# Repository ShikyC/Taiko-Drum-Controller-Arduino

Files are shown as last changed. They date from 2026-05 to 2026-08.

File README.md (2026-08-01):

> **Legacy implementation archived:** the old Arduino/ATmega32U4 and earlier ESP32 implementation from `master` has reached end of life and is archived on the [`archive-arduino-legacy` branch](https://github.com/ShikyC/Taiko-Drum-Controller-Arduino/tree/archive-arduino-legacy). This branch documents the refactored ESP-IDF implementation.

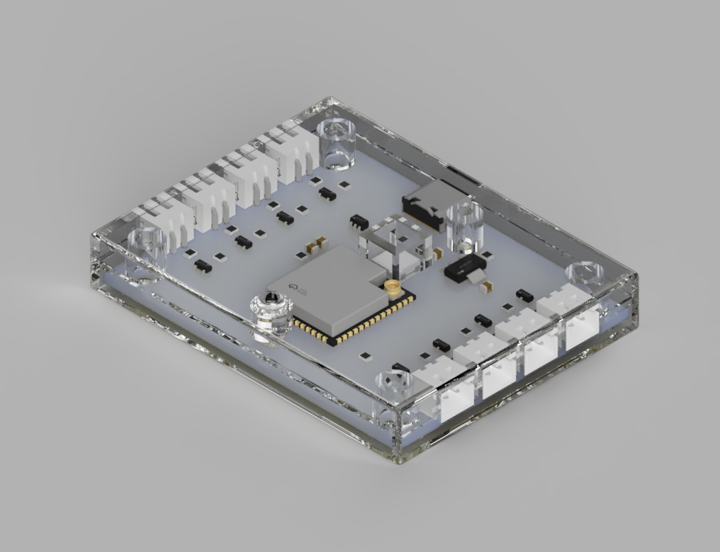
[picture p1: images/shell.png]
Taiko Drum Controller


# Taiko Drum Controller - ESP32-S3

Open-source firmware and hardware for building a USB taiko drum controller for PC play. Note that this controller **does not support Taiko no Tatsujin: Rhythm Festival** or **TJAPlayer**. This project is intended for Nijiiro-style, arcade-like computers. Full support for Rhythm Festival/TJAPlayer/Nintendo Switch/Playstation 4 is planned.

The firmware has been thoroughly tested with Taiko Force Lv. 5 and Lv. 6 drums. In theory, it works with other custom-made drums, but I haven't done any verification yet.

## Current Status

- [x] Supports Taiko Force Lv. 5/6 drum wiring through ESP32-S3 ADC continuous mode with DMA.
- [x] Processes two players with profiles calibrated against various 1P and 2P captures.
- [x] Sends analog hit strength through gamepad axes instead of keyboard events.
- [x] PCB Gerber files and BOM are available in [`PCB/`](./PCB/).
- [x] [3D printed shell](./PCB/3D_Print_Shell.3mf) is ready.
- [x] Shows status with the RGB LED.
- [ ] Adds buttons for other PC games/Nintendo Switch/Playstation 4 support.

## Hardware Support

The supported target is **ESP32-S3**.

Other ESP32 variants may work if they support the same ADC continuous mode, DMA behavior, USB device mode, and pin availability, but they are not tested. Arduino boards, ATmega32U4 boards, and non-USB ESP32 development boards are not supported by this firmware.

## Firmware Overview

The firmware in [`main/taiko_controller.c`](./main/taiko_controller.c) does seven main things:

1. Configures TinyUSB as a HID gamepad.
2. Configures ADC continuous sampling for eight drum sensor inputs.
3. Reassembles complete eight-channel scans independent of DMA frame boundaries.
4. Converts raw ADC readings through an eFuse-calibrated millivolt lookup table.
5. Runs baseline removal, a 0.96 ms RMS window, winner selection, and hit/rearm state through the platform-independent processor in [`main/taiko_hit_processor.c`](./main/taiko_hit_processor.c).
6. Publishes the winning zone and strength through signed gamepad axes.
7. Notifies a lower-priority, core-isolated RMT worker that drives the shared hit indicator without blocking ADC processing.

The current sampling model is:

- `PLAYERS`: `2`
- `CHANNELS_PER_PLAYER`: `4`
- `TOTAL_CHANNELS`: `8`
- requested aggregate ADC rate: `83333` conversions/s
- actual aggregate ADC rate: `83333.333` conversions/s
- actual per-channel rate: `10416.667` samples/s
- conversion spacing: `12 us`
- `USB_REPORT_INTERVAL_US`: `1000`
- detector integration and capture latency: about `1.73 ms`
- output hold: `12 ms`
- standard-profile refractory interval: `12 ms`
- long-tail-profile refractory interval: `72 ms`

Each player has four zones:

1. Left don
2. Left ka
3. Right don
4. Right ka

Only the strongest zone for each player is emitted in each HID report. Don zones are sent as positive axis values and ka zones are sent as negative axis values.

## Pin Map

The default ADC pin map uses ADC1 GPIOs on ESP32-S3 and avoids the native USB pins.

| Player | Zone | GPIO |
| --- | --- | --- |
| P1 | Left don | 3 |
| P1 | Left ka | 4 |
| P1 | Right don | 5 |
| P1 | Right ka | 6 |
| P2 | Left don | 7 |
| P2 | Left ka | 8 |
| P2 | Right don | 9 |
| P2 | Right ka | 10 |
| Shared | RGB LED data | 38 |

Debug outputs:

| GPIO | Meaning |
| --- | --- |
| 1 | High when the ADC DMA pool overflows or an ADC read fails |
| 2 | High when the USB HID host is not ready |

If you change pins, use ADC-capable pins for the selected ESP32-S3 board and keep GPIO 19/20 free for native USB unless your board routes USB differently.

The addressable RGB LED uses 24-bit `GRB` data. Each accepted Don hit holds red for 120 ms and each accepted Ka hit independently holds blue for 120 ms. If those windows overlap across either player, both channels remain active and the LED displays purple.

## Requirements

- ESP32-S3 development board with native USB device support.
- ESP-IDF 5.x environment.
- Four piezo sensors per drum, eight total for two-player support.

Hardware files:

- Project PCB, Gerber archive, and BOM are available in [`PCB/`](./PCB/).
- (Optional) 3D printed shell.

## PCB

The current PCB package is available under [`PCB/`](./PCB/):

- [`PCB/PCB.png`](./PCB/PCB.png): PCB preview image.
- [`PCB/Taiko_DMA_PCB.zip`](./PCB/Taiko_DMA_PCB.zip): Gerber production archive.
- [`PCB/Taiko_DMA_BOM.xlsx`](./PCB/Taiko_DMA_BOM.xlsx): BOM spreadsheet.

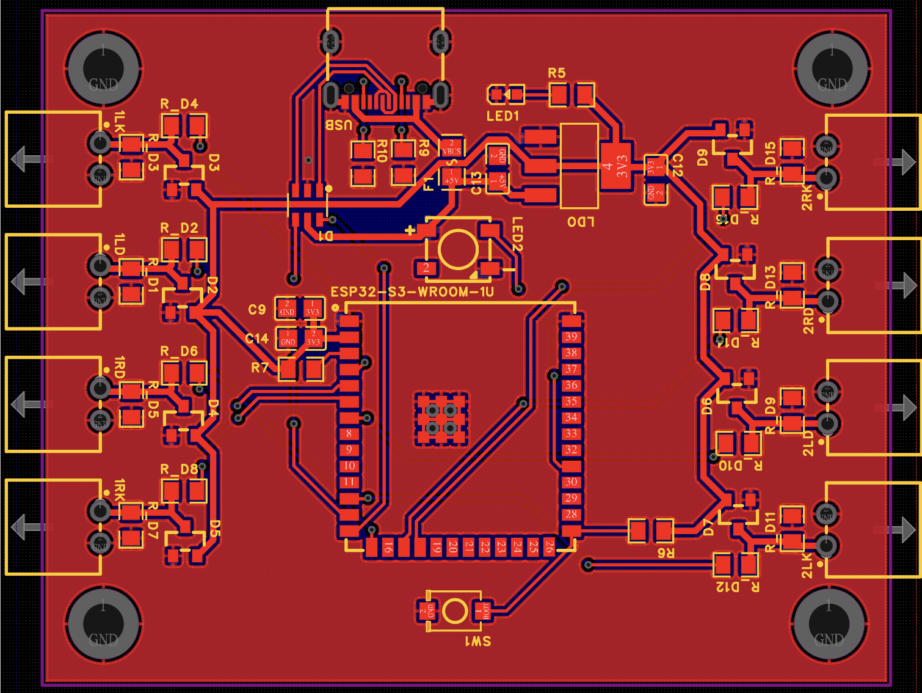
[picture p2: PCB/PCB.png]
Taiko DMA PCB


The board is designed around the ESP32-S3-WROOM-1U module and the DMA-based firmware in this repository. Review the BOM and board files before ordering or assembly, especially while the housing and final assembly guide are still in progress.

## 3D Printing

The [shell's 3MF file](./PCB/3D_Print_Shell.3mf) is ready to be used with any slicer software and 3D printers. Tested with PLA. Note that for the best result, use 0.2mm nozzle. Larger nozzle can cause some thin walls to be broken.

To finish the build, in addition to the PCB BOM, you'll need:

- M3 countersunk screw x 4
- M3 heat inserts x 4

An assembled example is shown below.

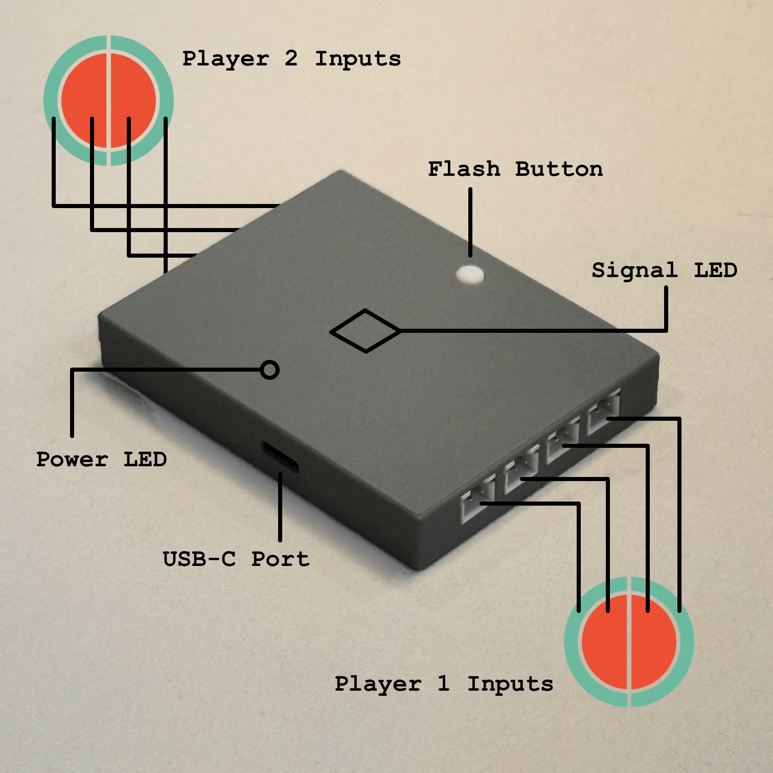
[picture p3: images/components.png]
Example


## Build and Flash

Install and activate ESP-IDF, then build for ESP32-S3:

```sh
idf.py set-target esp32s3
idf.py build
```

If you see build errors, make sure to set the following [`sdkconfig.defaults`](./sdkconfig.defaults) value:

```ini
CONFIG_TINYUSB_HID_COUNT=1
```

To enter flashing mode, press and hold the flash button, then plug in the USB cable, and flash the firmware:

```sh
idf.py flash
```

After flashing, unplug and replug in the USB cable (without holding the flash button). You will see an HID gamepad called "Taiko Controller" connected.

## Development

For online debugging, use [this tool](https://shiky.me/taiko). For deeper debugging, you'll need an ESP32-S3 development board, as the production PCB lacks the serial port. 

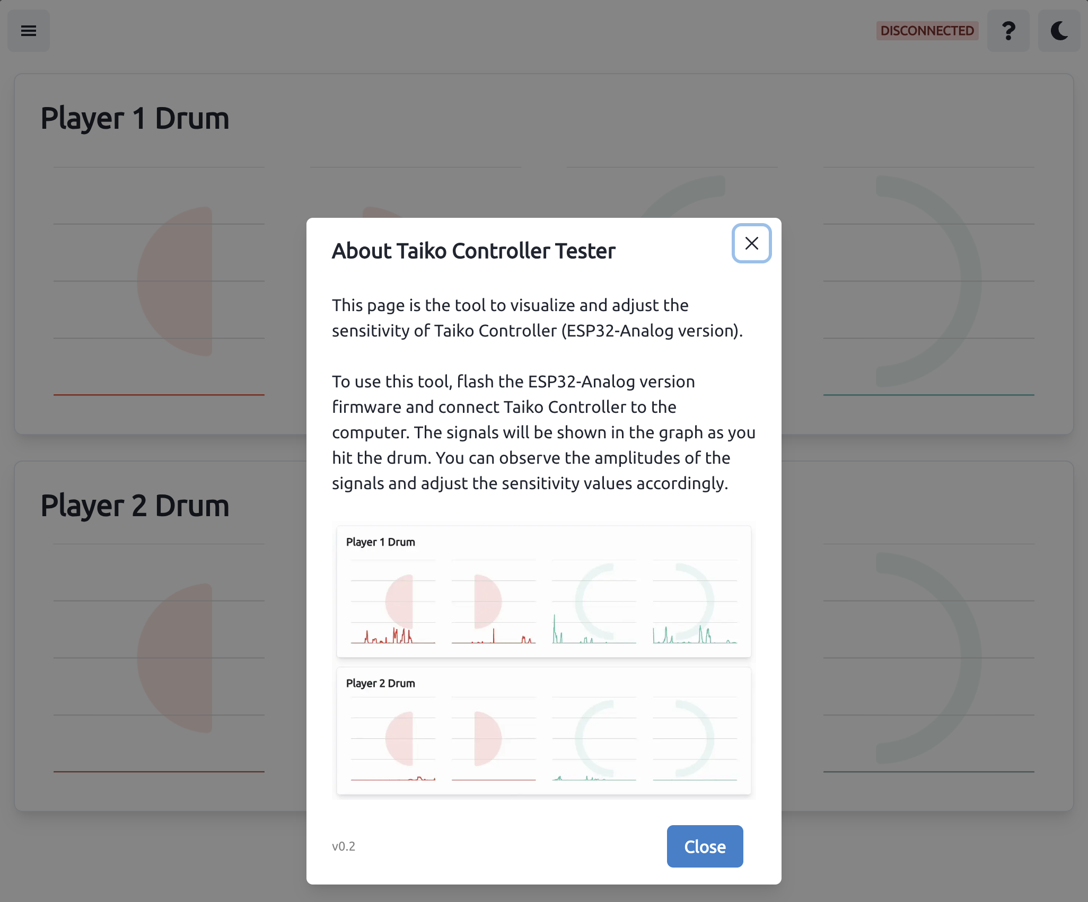
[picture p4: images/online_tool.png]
Online tool


## Gamepad Output

The USB device descriptor is configured as:

- Manufacturer: `Taiko Community`
- Product: `Taiko Controller`
- VID: `0x4869`
- PID: `0x4869`

Current axis mapping:

| Player | Zone | HID output |
| --- | --- | --- |
| P1 | Left don | `+X` |
| P1 | Left ka | `-X` |
| P1 | Right don | `+Y` |
| P1 | Right ka | `-Y` |
| P2 | Left don | `+Rx` |
| P2 | Left ka | `-Rx` |
| P2 | Right don | `+Ry` |
| P2 | Right ka | `-Ry` |

## Tuning

Choose the compile-time preset in [`main/taiko_controller.c`](./main/taiko_controller.c):

```c
#define HIT_SENSITIVITY TAIKO_SENSITIVITY_BALANCED
```

Available presets are `TAIKO_SENSITIVITY_SENSITIVE`, `TAIKO_SENSITIVITY_BALANCED`, and `TAIKO_SENSITIVITY_FIRM`. They differ in incidental-contact rejection and axis scaling; Balanced is the default. The thresholds and per-channel gains live in [`main/taiko_hit_processor.c`](./main/taiko_hit_processor.c).

Select the standard or long-tail processing profile independently for each drum:

```c
#define P1_USE_LONG_TAIL_PROFILE false
#define P2_USE_LONG_TAIL_PROFILE true
```

The standard profile uses the selected sensitivity preset and a 12 ms refractory interval. The long-tail profile uses firm thresholds and a 72 ms refractory interval so that the noisier decay remains part of the original strike instead of becoming extra hits. The default selects the standard profile for P1 and the long-tail profile for P2. Profile selection only changes each processor's initialization data; it adds no work, task, or synchronization to the real-time ADC loop.

Host replay tested 100 ADC start phases in both supported channel orders. The standard profile recognized all 6,400 phase-augmented 1P hits with no wrong zones, misses, or false positives; the long-tail profile did the same for all 6,400 2P hits. These captures contain isolated strikes. Because the 72 ms interval intentionally limits the long-tail profile to roughly 14 distinct hits per second per player, dense rolls should be recorded and added to the acceptance corpus before reducing it.

## Signal Conditioning Notes

Piezo sensors can produce voltage outside the safe ADC input range. Protect the ESP32-S3 ADC inputs before connecting a drum directly.

The legacy implementation documented bridge rectifiers because raw piezo output can swing negative and lose useful signal when clipped by the ADC. That concern still applies at the hardware level, but the new firmware is centered on high-rate ADC sampling rather than the old Arduino threshold detector.

Even with the PCB package available, treat the wiring and analog front end as experimental until the housing and final assembly guide are finished.

## Credits

- The PCB design is based on the open-source ESP32-S3 minimal system board project published on OSHWHub: [esp32s3-zui-xiao-xi-tong-ban-20241211](https://oshwhub.com/sun1053/esp32s3-zui-xiao-xi-tong-ban-20241211).
- The ADC DMA implementation is based on Espressif's official ESP-IDF ADC continuous mode example code.

## Appendix: Game Integration Notes

You will need a compatible [Taiko Arcade Loader](https://github.com/esuo1198/TaikoArcadeLoader) library to make the controller work with the game instance. After importing the required files, open the `gamecontrollerdb.txt` file and add this following line:

```
030052a8694800006948000000000000,Taiko Controller,-leftx:-a0,+leftx:+a0,-lefty:-a1,+lefty:+a1,-rightx:-a2,+rightx:+a2,-righty:-a3,+righty:+a3,platform:Windows,
```

Then, open `config.toml`, find the `[controller]` section, set `analog_input = true`. This will disable button input for the game and use analog axes' inputs. Now you can start the game and try out the new controller!

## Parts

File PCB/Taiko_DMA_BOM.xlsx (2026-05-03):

No. | Quantity | Comment | Designator | Footprint | Value | Manufacturer Part | Manufacturer | Supplier Part | Supplier
1 | 8 | XH-2AW | 1LD,1LK,1RD,1RK,2LD,2LK,2RD,2RK | CONN-TH_XH-2AW_C2908611 |  | XH-2AW | HCTL(华灿天禄) | C2908611 | LCSC
2 | 3 | 10uF | C9,C12,C13 | C0805 | 10uF | CL21A106KAYNNNE | SAMSUNG(三星) | C15850 | LCSC
3 | 1 | 100nF | C14 | C0805 | 100nF | CC0805KRX7R9BB104 | YAGEO(国巨) | C49678 | LCSC
4 | 1 | USBLC6-2SC6 | D1 | SOT-23-6_L2.9-W1.6-P0.95-LS2.8-BL |  | USBLC6-2SC6 | UMW(友台半导体) | C2687116 | LCSC
5 | 8 | BAT54SLT1G | D2,D3,D4,D5,D6,D7,D8,D9 | SOT-23_L2.9-W1.3-P1.90-LS2.4-BR |  | BAT54SLT1G | onsemi(安森美) | C19726 | LCSC
6 | 1 | 2.4GHz | ESP32-S3-WROOM-1U | WIRELM-SMD_ESP32-S3-WROOM-1U | 2.4GHz | ESP32-S3-WROOM-1U-N16R8 | ESPRESSIF(乐鑫) | C3013946 | LCSC
7 | 1 | BSMD0805-050-24V | F1 | F0805 |  | BSMD0805-050-24V | BHFUSE(佰宏) | C910822 | LCSC
8 | 1 | AMS1117-3.3 | LDO | SOT-223-3_L6.5-W3.4-P2.30-LS7.0-BR |  | AMS1117-3.3 | AMS | C6186 | LCSC
9 | 1 | NCD0603R1 | LED1 | LED0603-RD_RED |  | NCD0603R1 | 国星光电 | C84263 | LCSC
10 | 1 | XL-5050RGBC-2812B | LED2 | LED-SMD_4P-L5.0-W5.0-BL_XL-5050RGBC |  | XL-5050RGBC-2812B | XINGLIGHT(成兴光) | C2843785 | LCSC
11 | 1 | 1kΩ | R5 | R0805 | 1kΩ | 0805W8F1001T5E | UNI-ROYAL(厚声) | C17513 | LCSC
12 | 2 | 10kΩ | R6,R7 | R0805 | 10kΩ | 0805W8F1002T5E | UNI-ROYAL(厚声) | C17414 | LCSC
13 | 2 | 5.1kΩ | R9,R10 | R0805 | 5.1kΩ | 0805W8F5101T5E | UNI-ROYAL(厚声) | C27834 | LCSC
14 | 8 | 47kΩ | R_D1,R_D3,R_D5,R_D7,R_D9,R_D11,R_D13,R_D15 | R0805 | 47kΩ | 0805W8F4702T5E | UNI-ROYAL(厚声) | C17713 | LCSC
15 | 8 | 2.2kΩ | R_D2,R_D4,R_D6,R_D8,R_D10,R_D12,R_D14,R_D16 | R0805 | 2.2kΩ | 0805W8F2201T5E | UNI-ROYAL(厚声) | C17520 | LCSC
16 | 1 | TS-1088-AR02016 | SW1 | SW-SMD_L3.9-W3.0-P4.45 |  | TS-1088-AR02016 | XUNPU(讯普) | C720477 | LCSC
17 | 1 | TYPE-C 16PIN 2MD(073) | USB | USB-C-SMD_TYPE-C-6PIN-2MD-073 |  | TYPE-C 16PIN 2MD(073) | SHOU HAN(首韩) | C2765186 | LCSC

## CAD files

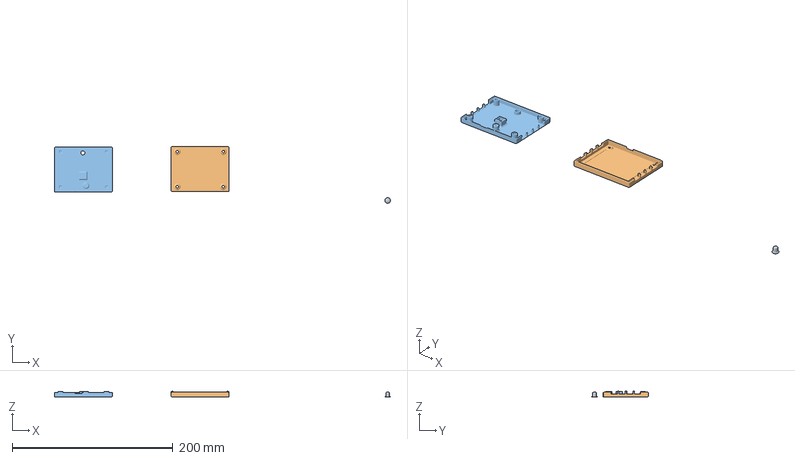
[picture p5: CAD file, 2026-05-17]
PCB/3D_Print_Shell.3mf
418.4 x 70.5 x 8.00 mm
Flash Button
Bottom
Top

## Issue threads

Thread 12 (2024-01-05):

Update 2 drum mode for other boards

ShikyC, 2024-01-05:

sorrowfullys, 2024-01-27:
新更新的pcb文件已经下单制作了，元器件也买好了，新入手了esp32 ，想问下这个电路板做好后，也可以刷单人键盘模拟么，[ESP32-S3.ino]这个是否适用您新增的pcb

ShikyC, 2024-01-28:
@sorrowfullys 哇你这速度也太快了，我也才刚在嘉立创下单……理论上依然可以模拟键盘，你把不过在这之前有个很重要的事情是你要的ESP32-S3开发板的尺寸和针脚和我的要一样才行（22针脚长，10针脚宽，以及针脚的顺序也要一致。我这块PCB不适配ESP32和ESP32-S2，只能用S3的。

ShikyC, 2024-01-28:
@sorrowfullys 我用的是这块板子：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

sorrowfullys, 2024-01-28:
太好了，中文交流，应该是一样的，单排也买的22p的，可调电阻我买的10k和50k的，我自己设计的pcb没有可调电阻，用的32u4，发现改灵敏值后，键位就乱窜，哪怕改0.1都不行，不知道什么原因，然后那个可视化观察数值的，一直反复快速刷新，观察不到有效数字，可以探讨交流下么，qq541784531，街机鼓的木板尺寸我已经还原了，也定制了，我做的是带钢板的版本，包括减震垫的非标规格也有厂家可以做，直型的减震垫太硬了，虽然便宜
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

ShikyC, 2024-01-29:
@sorrowfullys 我重构整合了一下，之前数值乱跳以及有一侧没反应应该是因为有个针脚被我改来改去搞乱了，现在应该好了……过两天会抽空更新一下文档详细说一下怎么用（你也可以看注释自己调试一下先）。
时间关系我现在只测试了两个模式（单鼓实时调节灵敏度/双鼓预烧录灵敏度）在虹CHN版+原生力度感应输入（替换我提供的那个dll文件）基本完美了，但是模拟成键盘玩次郎或者模拟器之类的我还没来得及测，不确定还能不能用

sorrowfullys, 2024-01-29:
@ShikyC 新的你设计的那个电路板没有问题对吧，照做照焊就行

ShikyC, 2024-01-30:
@sorrowfullys 理论上没问题，不过我还没收到打样，不敢100%说没问题……

sorrowfullys, 2024-01-30:
@ShikyC 你有没有看那个taiko input的项目，感觉那个方案很完善，只是电路板焊接可能需要加热平台
你这个板子应该明天到，其他配件也这两天到，到时候刷写调试代码可以咨询下你么

sorrowfullys, 2024-01-30:
@ShikyC  qq  541784531

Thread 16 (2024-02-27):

敲擊感應電路相關問題

HellbroWDR, 2024-02-27:
作者您好，我參考了您的文檔搭建了使用橋式整流器的電路。使用的板子是arduino leonardo，橋式整流器使用的是DB105(店家DB107缺貨)，電阻使用100k歐姆。
目前遇到的問題是，沒有裝橋式整流器的話，敲擊可以感測到，但是有裝的話就感應不到敲擊。想請問作者有遇到這種狀況嗎？

ShikyC, 2024-02-29:
Please first check the output of the rectifier (with a multimeter or an oscilloscope) to verify it's working. Also, please note although the input polarity doesn't matter, the output DOES. You should connect `+` to an analog input pin and `-` to the ground. Can you show me a picture of your circuit?

HellbroWDR, 2024-02-29:
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
棕線接analog input，黑線接GND

ShikyC, 2024-03-01:
Can you test the direct output of the rectifier with a multimeter? Using voltage mode, measure the value between `+` and `-` while you hit the drum. Although not accurate, you should be able to see a value change. If not, the rectifier chip might not work for you.
You can also remove the resistors and connect `+` directly to the analog input of your Leonardo board (unlike ESP32, ATmega32 boards measure analog inputs from 0 to 5V so you don't need to scale down the input voltage) to ensure that it wasn't the issue of the resistors.

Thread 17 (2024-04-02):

关于压电传感器型号

EnTaroYan, 2024-04-02:
作者您好，我参考了您的文章，打算使用您分享的PCB电路图也自己制作一个鼓，可以分享一下您的压电传感器型号吗？ 谢谢~

ShikyC, 2024-04-03:
所有的元器件请参考这个[物料清单](https://github.com/ShikyC/Taiko-Drum-Controller-Arduino/blob/master/ESP32-S3-Analog/PCB/BOM_PCB_Taiko%20Controller_2_2024-01-26.csv)。整流桥我用的是[这款ABS10](https://www.lcsc.com/product-detail/Bridge-Rectifiers_Guangdong-Hottech-ABS10_C190798.html)。

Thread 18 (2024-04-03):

Getting constant output from Serial Monitor in DEBUG mode

mechachoi, 2024-04-03:
Hello ShikyC,

Thank you so much for developing this. I am very passionate about getting my own taiko setup up and running.

I have my Taiko (an official arcade taiko) connected to my circuit with bridge rectifiers. I am seeing approximately 4V constant voltage out of the output of the rectifiers when I put my multimeter across it, but I do see a change when I strike the drum in the respective locations.

However, whenever I open the serial monitor to see what is happening in DEBUG mode, I am getting basically constant values from the Serial Monitor, 126945 just over and over again. I'm trying to figure out what's going on that would cause this behavior.

If I change one of the sensitivities of one of the sections of the drum, all the values change.

mechachoi, 2024-04-04:
Doesn't the piezo drum need some kind of powered circuit to output signal?

ShikyC, 2024-04-04:
No. Unlike active input sources (such as microphones), piezoelectric sensors produces periodic voltage by themselves as if they're power sources.

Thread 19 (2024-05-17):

Request for Centroid (Pick-and-Place) File

Dennisjoch, 2024-05-17:
Hello,

I am currently using the PCB design files from this project, but I need a Centroid (Pick-and-Place) file for assembly purposes. Unfortunately, I only have the Gerber files and do not have the original PCB design files to generate the Centroid file myself.

Would it be possible for you to provide a Centroid file for this project?

Thank you very much for your assistance!

Best regards, Dennis Joch

ShikyC, 2024-05-22:
Unfortunately I have been modifying the origianl PCB project recently for a new release so I can't generate the Centroid fild for this version.

My suggestion is, because the PCB is so simple that you can buy the components listed in the BOM file and hand-solder it. Or if you need it urgently and live in the U.S., I can ship one to you for free (excluding the shipping fee).

Dennisjoch, 2024-05-23:
Hey, it's all good. After some head-scratching and overpriced offers on Fiverr, the customer support from PCBWay got in touch and was able to help me based on your project preview image and my labeling. Just as I was about to cancel the assembly because I thought I'd have to solder it myself. Thank you for your willingness to help, and great project! Thanks.

Closed 2024-05-23.

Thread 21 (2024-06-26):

No Keyboard output-ESP32 wroom 30 pin cp2102

REZICIAK2, 2024-06-26:
after setting up the code and correcting it so i dont have any ghost inputs or too sensitive sensors i dont get any outputs, in fact i didnt have them even after i ulpoaded the downloaded code without changing it
my parameters
#define HIT_THRES 900
#define RESET_THRES 500
define SAMPLE_CACHE_LENGTH 32

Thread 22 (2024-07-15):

关于传感器信号干扰到其他传感器的问题

Steve-xmh, 2024-07-15:
大佬你好，首先非常感谢大佬能够提供这样的一个项目代码供参考！我参考了你的源代码编写了基于 ESP-IDF 框架的模拟信号实现，但是遇到了传感器信号（串音）相互干扰的问题（敲击某个传感器时，会影响其他传感器的数值，即便其他传感器并没有被敲击），想询问大佬可能的问题和错误的检查流程。

我使用的传感器是 muRata 的震动传感器（应该是官方街机使用的版本，为了方便连接我改装并延长了原先的线材，引成了两根杜邦公头线）：
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

然后通过 [Taiko Controller Test](https://shiky.me/taiko) 页面检测的数据大概是这样的（只对右侧鼓面（右咚）的传感器敲击）：

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

并且信号在敲击之后是缓慢下降才归零的，不清楚是不是传感器被我改动过了的缘故：

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

开发板我使用的是微雪电子的 ESP32-S3-Zero，并将 GPIO1-4 引脚用于连接传感器（正极连接了 3V3 引脚）输入模拟信号。

大概实物连接的样子是这样的：

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

如果还需要其他信息请不吝指教，非常感谢！

Steve-xmh, 2024-07-17:
更新一下，我把代码重构成了使用 ADC 持续读取方式，再修改了一下连接方式后不会那么容易出现到干扰其他传感器信号的情况了，但是信号缓慢下降的情况还没有头绪：

（蓝色圈起部分为用手指敲击传感器的时间刻）
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

ShikyC, 2024-07-20:
不好意思来晚了，最近刚毕业入职有点忙……我不确定这种信号缓慢damping的现象是不是振动传感器上其他元器件导致的（我的板子设计没考虑这些因素，就是简单的让压电陶瓷片直连ADC），但如果这是官方鼓用的传感器的话那可能从压电陶瓷出来会有匹配阻抗或者滤波的元件。你能发一下这个传感器的data sheet吗，我这周末有时间看一下

Steve-xmh, 2024-07-20:
> 不好意思来晚了，最近刚毕业入职有点忙……我不确定这种信号缓慢damping的现象是不是振动传感器上其他元器件导致的（我的板子设计没考虑这些因素，就是简单的让压电陶瓷片直连ADC），但如果这是官方鼓用的传感器的话那可能从压电陶瓷出来会有匹配阻抗或者滤波的元件。你能发一下这个传感器的data sheet吗，我这周末有时间看一下

感谢大佬回复！我确实是为了想使用接近的材料复现街机的感觉才参考网上的说明买了这样的传感器，因为也是网络上找到看上去类似的就买了所以不清楚具体的型号，不过好像都叫它 muRata PKS Shock Sensor，店家也没有写详细的信息，我购买的[淘宝页面是这个](https://item.taobao.com/item.htm?spm=a1z09.2.0.0.478b2e8dJ8OkCT&id=695496541914&_u=k3oh5kvocede)。

至于 Data Sheet 的话只能尽量找应该是同款的给大佬看看能不能作为参考了： https://octopart.com/datasheet/pks1-4a10-murata-5005343

（其实我是第一次尝试这样的硬件开发所以有很多不太懂的地方，如果哪里写的不是很对还请多多指教）

> 其实昨天刚想起来自己参考代码的时候没有理解那个 ADC 取值的用法，我是直接把 ADC 的取值简单限制范围然后直接当作摇杆输入了，没留意大佬其实是把差值拿来用，等回头电脑在身边的时候我再修改一下代码看看能不能有所改善这个情况。

ShikyC, 2024-07-20:
啊我好像发现你电路的问题了……看图虽然不太好猜，不过听你描述你是不是把3.3V电压加到压电陶瓷片上了？压电陶瓷片本你可以理解为是一个电压源，不需要外接电源的。直接一头接GPIO另一头接地就行了。
考虑到ESP32的ADC最大输入只有3.3V，压电陶瓷的瞬时电压可能会超过这个数（我自己测大概是0～5V的范围）所以可以接两个电阻分压（不用也行，烧毁的风险很低）。
希望能帮到你！我也打算买几个你说的这个传感器回头看看怎么辉石

Steve-xmh, 2024-07-21:
> 啊我好像发现你电路的问题了……看图虽然不太好猜，不过听你描述你是不是把3.3V电压加到压电陶瓷片上了？压电陶瓷片本你可以理解为是一个电压源，不需要外接电源的。直接一头接GPIO另一头接地就行了。 考虑到ESP32的ADC最大输入只有3.3V，压电陶瓷的瞬时电压可能会超过这个数（我自己测大概是0～5V的范围）所以可以接两个电阻分压（不用也行，烧毁的风险很低）。 希望能帮到你！我也打算买几个你说的这个传感器回头看看怎么辉石

一语道破，我确实是接到了 3V3 的孔，重新接地之后现在信号下降的情况有了很大的改善。但是敲击一个传感器导致其他传感器也一起感应出信号的情况还是存在，还是要找一下原因（图中敲击了鼓边传感器但是鼓面传感器也发生的感应）：

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

ShikyC, 2024-07-22:
这个其实不是问题，你只需要通过调整灵敏度，确保每次敲击时，**数值最大的面就是你敲级的面**就行了，游戏内置的IO机制会自动触发这个敲击并忽略其他敲击。啊当然前提是你玩的是你懂的那个08.18游戏版本并且替换`bnusio.dll`文件。（按理说应该对几个月前新泄露的24版游戏也能用，我还没试过不确定）。
如果你玩第三方游戏（TJAPlayer或者次郎）就要刷模拟成键盘的那个版本的固件了（调试比较麻烦，只能用串口通信），不过逻辑是一样的，保证敲哪边哪个数值最大即可。

Steve-xmh, 2024-07-22:
> 这个其实不是问题，你只需要通过调整灵敏度，确保每次敲击时，**数值最大的面就是你敲级的面**就行了，游戏内置的IO机制会自动触发这个敲击并忽略其他敲击。啊当然前提是你玩的是你懂的那个08.18游戏版本并且替换`bnusio.dll`文件。（按理说应该对几个月前新泄露的24版游戏也能用，我还没试过不确定）。 如果你玩第三方游戏（TJAPlayer或者次郎）就要刷模拟成键盘的那个版本的固件了（调试比较麻烦，只能用串口通信），不过逻辑是一样的，保证敲哪边哪个数值最大即可。

这样子，那我就多花心思去调试一下就行，那议题就差不多就解决了，非常感谢！

Steve-xmh, 2024-07-22:
啊还是返回来说明一下这个现象，经常出现以下情况：
- 敲鼓边数次，有点反应，然后另外三个传感器一起有感应而且比这个鼓边还高
- 敲鼓面，四个传感器一起有大小不一的感应抖动
- 快速敲击多次，漏拍现象严重
诸如以上的情况，感觉不像是简单调节传感器灵敏度就能解决的情况（）

Closed 2024-07-22.

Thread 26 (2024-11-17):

Not getting inputs in certain Games

loading175, 2024-11-17:
Hello ShikyC,

thank you for developing this. Im a big Taiko fan and very happy that this repo exists. My drum and the inputs work in Windows. If i open up Notepad and hit the drums i'm getting the correct outputs.

However this is the Problem i encounter, im currently using an ESP32S3 and the `ESP32S3 non-analog` version:
Certain games (for example Osu!Stable) as well as every game in steam I tested (among those games: Taiko no Tatsujin Rythm Festival) don't accept the inputs from the drum. Steam games ignore input from the drum entirely as soon as you start a game.
In Osu!Stable typing in the menu is possible but as soon as you start a map it disables all inputs from the drum aswell.

What could be the problem?

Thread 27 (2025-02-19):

calibration settings dont work

SatsukiRyu, 2025-02-19:
if i change these to other numbers than 1 (normal) 0 (off) the sensibility goes too hight even 0.1

```
// Sensitivity multipliers for each channel, 1.0 as the baseline
#define L_DON_SENS 1
#define L_KAT_SENS 1
#define R_DON_SENS 1
#define R_KAT_SENS 1

```

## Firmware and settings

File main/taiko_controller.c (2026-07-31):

#include <stdbool.h>
#include <stdint.h>
#include <string.h>

#include "class/hid/hid_device.h"
#include "driver/gpio.h"
#include "esp_adc/adc_cali.h"
#include "esp_adc/adc_cali_scheme.h"
#include "esp_adc/adc_continuous.h"
#include "esp_heap_caps.h"
#include "esp_timer.h"
#include "freertos/FreeRTOS.h"
#include "freertos/task.h"
#include "hal/adc_types.h"
#include "soc/soc_caps.h"
#include "taiko_hit_led.h"
#include "taiko_hit_processor.h"
#include "tinyusb.h"
#include "tinyusb_default_config.h"

#define DEBUG_PIN_1 GPIO_NUM_1  // HIGH on ADC DMA/read error
#define DEBUG_PIN_2 GPIO_NUM_2  // HIGH while the USB HID host is not ready

/************* TinyUSB descriptors ****************/

enum {
    ITF_NUM_HID,
    ITF_NUM_TOTAL,
};

#define EPNUM_HID 0x81
#define TUSB_DESC_TOTAL_LEN (TUD_CONFIG_DESC_LEN + TUD_HID_DESC_LEN)

#define USB_VID 0x4869
#define USB_PID 0x4869
#define USB_REPORT_INTERVAL_US 1000

/************* ADC and detector configuration ****************/

#define PLAYERS 2
#define CHANNELS_PER_PLAYER TAIKO_CHANNELS_PER_PLAYER
#define TOTAL_CHANNELS (PLAYERS * CHANNELS_PER_PLAYER)

// ESP32-S3's ADC digital controller uses a 2.5 MHz trigger timer. ESP-IDF
// accepts 83,333 here, programs interval 30, and the resulting conversion
// rate is 83,333.333 Hz (10,416.667 complete samples/s for each of 8 inputs).
#define ADC_REQUESTED_CONVERSION_RATE_HZ 83333UL
#define ADC_SCANS_PER_DMA_FRAME 8
#define DMA_CONVERSIONS_PER_FRAME (TOTAL_CHANNELS * ADC_SCANS_PER_DMA_FRAME)
#define DMA_FRAME_BYTES (DMA_CONVERSIONS_PER_FRAME * SOC_ADC_DIGI_RESULT_BYTES)
#define DMA_STORE_BUFFER_BYTES (DMA_FRAME_BYTES * 8)
#define ADC_READ_TIMEOUT_MS 2
#define ADC_ATTEN_DB ADC_ATTEN_DB_12
#define ADC_BIT_WIDTH ADC_BITWIDTH_12
#define HIT_SENSITIVITY TAIKO_SENSITIVITY_BALANCED
// Long-tail profile is only needed for old drums like Taiko Force Lv. 5 for
// backward-compatibility. For newer models like Lv. 6 or other brands, this
// is not needed.
#define P1_USE_LONG_TAIL_PROFILE false
#define P2_USE_LONG_TAIL_PROFILE false
#define ADC_RAW_LEVELS (1U << 12)
#define NOMINAL_ADC_FULL_SCALE_MV 3100U

typedef struct __attribute__((packed)) {
    int8_t x;
    int8_t y;
    int8_t z;
    int8_t rz;
    int8_t rx;
    int8_t ry;
    uint8_t hat;
    uint32_t buttons;
} taiko_hid_report_t;

// Each player's four channels are contiguous. Within a player, mechanically
// coupled same-side sensors are adjacent in the ADC pattern.
static const int kChannelGpios[TOTAL_CHANNELS] = {
    3, 4, 5, 6,  // P1 L-Don, L-Ka, R-Don, R-Ka
    7, 8, 9, 10  // P2 L-Don, L-Ka, R-Don, R-Ka
};

// Select the 72 ms tail-suppression profile independently for each drum.
static const bool kUseLongTailProfile[PLAYERS] = {
    P1_USE_LONG_TAIL_PROFILE,
    P2_USE_LONG_TAIL_PROFILE,
};

static adc_continuous_handle_t s_adc_handle;
static TaskHandle_t s_adc_task_handle;
static int8_t s_pattern_slot_by_adc_channel[SOC_ADC_CHANNEL_NUM(0)];
static volatile bool s_adc_pool_overflow;
static taiko_hit_processor_t s_hit_processors[PLAYERS];
static uint32_t s_published_outputs[PLAYERS];
static uint16_t s_adc_millivolts[ADC_RAW_LEVELS];

static const uint8_t hid_report_descriptor[] = {
    TUD_HID_REPORT_DESC_GAMEPAD(HID_REPORT_ID(0x01))
};

static const tusb_desc_device_t device_descriptor = {
    .bLength = sizeof(device_descriptor),
    .bDescriptorType = TUSB_DESC_DEVICE,
    .bcdUSB = 0x0200,
    .bDeviceClass = TUSB_CLASS_UNSPECIFIED,
    .bDeviceSubClass = 0x00,
    .bDeviceProtocol = 0x00,
    .bMaxPacketSize0 = CFG_TUD_ENDPOINT0_SIZE,
    .idVendor = USB_VID,
    .idProduct = USB_PID,
    .bcdDevice = 0x0100,
    .iManufacturer = 0x01,
    .iProduct = 0x02,
    .iSerialNumber = 0x03,
    .bNumConfigurations = 0x01,
};

static const uint8_t hid_configuration_descriptor[] = {
    TUD_CONFIG_DESCRIPTOR(1, ITF_NUM_TOTAL, 0, TUSB_DESC_TOTAL_LEN,
                          TUSB_DESC_CONFIG_ATT_REMOTE_WAKEUP, 100),
    TUD_HID_DESCRIPTOR(ITF_NUM_HID, 4, false, sizeof(hid_report_descriptor),
                       EPNUM_HID, sizeof(taiko_hid_report_t), 1),
};

static const char *hid_string_descriptor[] = {
    (const char[]){0x09, 0x04},  // 0: English (0x0409)
    "Taiko Community",           // 1: Manufacturer
    "Taiko Controller",          // 2: Product
    "0001",                      // 3: Serial
    "Gamepad",                   // 4: HID Interface
};

/********* TinyUSB HID callbacks ***************/

uint8_t const *tud_hid_descriptor_report_cb(uint8_t instance) {
    (void)instance;
    return hid_report_descriptor;
}

uint16_t tud_hid_get_report_cb(uint8_t instance, uint8_t report_id,
                               hid_report_type_t report_type, uint8_t *buffer,
                               uint16_t reqlen) {
    (void)instance;
    (void)report_id;
    (void)report_type;
    (void)buffer;
    (void)reqlen;
    return 0;
}

void tud_hid_set_report_cb(uint8_t instance, uint8_t report_id,
                           hid_report_type_t report_type,
                           uint8_t const *buffer, uint16_t bufsize) {
    (void)instance;
    (void)report_id;
    (void)report_type;
    (void)buffer;
    (void)bufsize;
}

/********* ADC continuous sampling ***************/

static esp_err_t init_adc(void) {
    adc_continuous_handle_cfg_t handle_config = {
        .max_store_buf_size = DMA_STORE_BUFFER_BYTES,
        .conv_frame_size = DMA_FRAME_BYTES,
        .flags = {.flush_pool = 1},
    };
    ESP_ERROR_CHECK(adc_continuous_new_handle(&handle_config, &s_adc_handle));

    adc_digi_pattern_config_t pattern[TOTAL_CHANNELS] = {0};
    memset(s_pattern_slot_by_adc_channel, -1,
           sizeof(s_pattern_slot_by_adc_channel));

    for (int slot = 0; slot < TOTAL_CHANNELS; ++slot) {
        adc_unit_t unit;
        adc_channel_t channel;
        ESP_ERROR_CHECK(adc_continuous_io_to_channel(
            kChannelGpios[slot], &unit, &channel));
        if (unit != ADC_UNIT_1 || channel >= SOC_ADC_CHANNEL_NUM(0)) {
            return ESP_ERR_INVALID_ARG;
        }
        s_pattern_slot_by_adc_channel[channel] = slot;
        pattern[slot].atten = ADC_ATTEN_DB;
        pattern[slot].channel = channel;
        pattern[slot].unit = unit;
        pattern[slot].bit_width = ADC_BIT_WIDTH;
    }

    adc_continuous_config_t digital_config = {
        .pattern_num = TOTAL_CHANNELS,
        .adc_pattern = pattern,
        .sample_freq_hz = ADC_REQUESTED_CONVERSION_RATE_HZ,
        .conv_mode = ADC_CONV_SINGLE_UNIT_1,
        .format = ADC_DIGI_OUTPUT_FORMAT_TYPE2,
    };
    ESP_ERROR_CHECK(adc_continuous_config(s_adc_handle, &digital_config));
    return ESP_OK;
}

static void init_adc_calibration_lut(void) {
    adc_cali_handle_t calibration = NULL;
    const adc_cali_curve_fitting_config_t calibration_config = {
        .unit_id = ADC_UNIT_1,
        .chan = ADC_CHANNEL_0,
        .atten = ADC_ATTEN_DB,
        .bitwidth = ADC_BIT_WIDTH,
    };
    const bool calibrated =
        adc_cali_create_scheme_curve_fitting(
            &calibration_config, &calibration) == ESP_OK;

    for (uint32_t raw = 0; raw < ADC_RAW_LEVELS; ++raw) {
        int millivolts =
            (int)((raw * NOMINAL_ADC_FULL_SCALE_MV +
                   (ADC_RAW_LEVELS - 1U) / 2U) /
                  (ADC_RAW_LEVELS - 1U));
        if (calibrated) {
            int calibrated_millivolts = 0;
            if (adc_cali_raw_to_voltage(
                    calibration, (int)raw, &calibrated_millivolts) == ESP_OK &&
                calibrated_millivolts >= 0) {
                millivolts = calibrated_millivolts;
            }
        }
        s_adc_millivolts[raw] = (uint16_t)millivolts;
    }
}

static bool IRAM_ATTR on_conversion_done(
    adc_continuous_handle_t handle,
    const adc_continuous_evt_data_t *event_data,
    void *user_data) {
    (void)handle;
    (void)event_data;
    (void)user_data;
    BaseType_t awoken = pdFALSE;
    vTaskNotifyGiveFromISR(s_adc_task_handle, &awoken);
    return awoken == pdTRUE;
}

static bool IRAM_ATTR on_pool_overflow(
    adc_continuous_handle_t handle,
    const adc_continuous_evt_data_t *event_data,
    void *user_data) {
    (void)handle;
    (void)event_data;
    (void)user_data;
    s_adc_pool_overflow = true;
    BaseType_t awoken = pdFALSE;
    vTaskNotifyGiveFromISR(s_adc_task_handle, &awoken);
    return awoken == pdTRUE;
}

static uint32_t encode_output(taiko_hit_output_t output) {
    if (!output.active) {
        return 0;
    }
    return (1U << 31) | ((uint32_t)output.zone << 8) | output.axis_value;
}

static taiko_hit_output_t decode_output(uint32_t encoded) {
    if ((encoded & (1U << 31)) == 0) {
        return (taiko_hit_output_t){0};
    }
    return (taiko_hit_output_t){
        .active = true,
        .zone = (taiko_zone_t)((encoded >> 8) & 0xffU),
        .axis_value = (uint8_t)(encoded & 0xffU),
    };
}

static void process_complete_adc_scan(const uint16_t scan[TOTAL_CHANNELS]) {
    for (int player = 0; player < PLAYERS; ++player) {
        const uint16_t *player_samples =
            &scan[player * CHANNELS_PER_PLAYER];
        taiko_hit_event_t hit_event;
        if (taiko_hit_processor_push(
                &s_hit_processors[player], player_samples, &hit_event)) {
            taiko_hit_led_notify(hit_event.zone);
        }
        const taiko_hit_output_t output =
            taiko_hit_processor_get_output(&s_hit_processors[player]);
        __atomic_store_n(
            &s_published_outputs[player], encode_output(output), __ATOMIC_RELEASE);
    }
}

static void adc_reader_task(void *argument) {
    (void)argument;
    uint8_t *raw = heap_caps_malloc(
        DMA_FRAME_BYTES, MALLOC_CAP_8BIT | MALLOC_CAP_INTERNAL);
    if (raw == NULL) {
        gpio_set_level(DEBUG_PIN_1, 1);
        vTaskDelete(NULL);
        return;
    }

    uint16_t scan[TOTAL_CHANNELS] = {0};
    size_t expected_slot = 0;

    while (true) {
        ulTaskNotifyTake(pdTRUE, portMAX_DELAY);
        if (__atomic_exchange_n(
                &s_adc_pool_overflow, false, __ATOMIC_ACQ_REL)) {
            gpio_set_level(DEBUG_PIN_1, 1);
        }

        bool first_read = true;
        while (true) {
            uint32_t bytes_read = 0;
            const esp_err_t result = adc_continuous_read(
                s_adc_handle, raw, DMA_FRAME_BYTES, &bytes_read,
                first_read ? ADC_READ_TIMEOUT_MS : 0);
            first_read = false;

            if (result == ESP_ERR_TIMEOUT) {
                break;
            }
            if (result != ESP_OK) {
                gpio_set_level(DEBUG_PIN_1, 1);
                expected_slot = 0;
                break;
            }
            gpio_set_level(DEBUG_PIN_1, 0);

            const adc_digi_output_data_t *items =
                (const adc_digi_output_data_t *)raw;
            const size_t conversions =
                bytes_read / SOC_ADC_DIGI_RESULT_BYTES;
            for (size_t index = 0; index < conversions; ++index) {
                const uint8_t adc_channel = items[index].type2.channel;
                if (adc_channel >= SOC_ADC_CHANNEL_NUM(0)) {
                    expected_slot = 0;
                    continue;
                }
                const int slot =
                    s_pattern_slot_by_adc_channel[adc_channel];
                if (slot < 0 || slot >= TOTAL_CHANNELS) {
                    expected_slot = 0;
                    continue;
                }

                // DMA reads can begin at any pattern position. Discard a
                // partial scan and synchronize on slot zero.
                if ((size_t)slot != expected_slot) {
                    expected_slot = 0;
                    if (slot != 0) {
                        continue;
                    }
                }

                const uint16_t raw_sample = items[index].type2.data;
                scan[slot] =
                    s_adc_millivolts[raw_sample < ADC_RAW_LEVELS
                                         ? raw_sample
                                         : ADC_RAW_LEVELS - 1U];
                expected_slot++;
                if (expected_slot == TOTAL_CHANNELS) {
                    process_complete_adc_scan(scan);
                    expected_slot = 0;
                }
            }
        }
    }
}

/********* HID report publication ***************/

static void apply_player_output(
    taiko_hid_report_t *report, int player, taiko_hit_output_t output) {
    if (!output.active || output.axis_value == 0) {
        return;
    }

    int8_t *horizontal = player == 0 ? &report->x : &report->rx;
    int8_t *vertical = player == 0 ? &report->y : &report->ry;
    const int8_t value = (int8_t)output.axis_value;
    switch (output.zone) {
        case TAIKO_ZONE_LEFT_DON:
            *horizontal = value;
            break;
        case TAIKO_ZONE_LEFT_KA:
            *horizontal = -value;
            break;
        case TAIKO_ZONE_RIGHT_DON:
            *vertical = value;
            break;
        case TAIKO_ZONE_RIGHT_KA:
            *vertical = -value;
            break;
    }
}

static taiko_hid_report_t build_hid_report(void) {
    taiko_hid_report_t report = {0};
    for (int player = 0; player < PLAYERS; ++player) {
        const uint32_t encoded = __atomic_load_n(
            &s_published_outputs[player], __ATOMIC_ACQUIRE);
        apply_player_output(&report, player, decode_output(encoded));
    }
    return report;
}

static void hid_report_timer_cb(void *argument) {
    (void)argument;
    if (!tud_mounted()) {
        return;
    }
    if (tud_suspended()) {
        tud_remote_wakeup();
    }

    const bool host_ready = tud_hid_ready();
    gpio_set_level(DEBUG_PIN_2, host_ready ? 0 : 1);
    if (host_ready) {
        const taiko_hid_report_t report = build_hid_report();
        tud_hid_report(0x01, &report, sizeof(report));
    }
}

void app_main(void) {
    const gpio_config_t debug_gpio_config = {
        .pin_bit_mask =
            (1ULL << DEBUG_PIN_1) | (1ULL << DEBUG_PIN_2),
        .mode = GPIO_MODE_OUTPUT,
        .pull_up_en = GPIO_PULLUP_DISABLE,
        .pull_down_en = GPIO_PULLDOWN_DISABLE,
        .intr_type = GPIO_INTR_DISABLE,
    };
    ESP_ERROR_CHECK(gpio_config(&debug_gpio_config));

    tinyusb_config_t tinyusb_config = TINYUSB_DEFAULT_CONFIG();
    tinyusb_config.descriptor.device = &device_descriptor;
    tinyusb_config.descriptor.full_speed_config =
        hid_configuration_descriptor;
    tinyusb_config.descriptor.string = hid_string_descriptor;
    tinyusb_config.descriptor.string_count =
        sizeof(hid_string_descriptor) / sizeof(hid_string_descriptor[0]);
    ESP_ERROR_CHECK(tinyusb_driver_install(&tinyusb_config));

    for (int player = 0; player < PLAYERS; ++player) {
        const taiko_hit_config_t hit_config =
            kUseLongTailProfile[player]
                ? taiko_hit_long_tail_config()
                : taiko_hit_config_for_sensitivity(HIT_SENSITIVITY);
        taiko_hit_processor_init(&s_hit_processors[player], &hit_config);
    }
    // The indicator is deliberately optional; ADC and HID operation continues
    // even if its low-priority worker cannot be created.
    (void)taiko_hit_led_start();

    ESP_ERROR_CHECK(init_adc());
    init_adc_calibration_lut();
    const UBaseType_t adc_task_priority = 4;
    if (xTaskCreatePinnedToCore(
            adc_reader_task, "adc_reader", 4096, NULL, adc_task_priority,
            &s_adc_task_handle, 0) != pdPASS) {
        return;
    }

    const adc_continuous_evt_cbs_t callbacks = {
        .on_conv_done = on_conversion_done,
        .on_pool_ovf = on_pool_overflow,
    };
    ESP_ERROR_CHECK(
        adc_continuous_register_event_callbacks(s_adc_handle, &callbacks, NULL));
    ESP_ERROR_CHECK(adc_continuous_start(s_adc_handle));

    // Let the baseline estimator observe quiet samples before publishing.
    vTaskDelay(pdMS_TO_TICKS(2));

    const esp_timer_create_args_t timer_args = {
        .callback = hid_report_timer_cb,
        .dispatch_method = ESP_TIMER_TASK,
        .name = "hid_report",
    };
    esp_timer_handle_t hid_timer;
    ESP_ERROR_CHECK(esp_timer_create(&timer_args, &hid_timer));
    ESP_ERROR_CHECK(
        esp_timer_start_periodic(hid_timer, USB_REPORT_INTERVAL_US));

    while (true) {
        vTaskDelay(portMAX_DELAY);
    }
}

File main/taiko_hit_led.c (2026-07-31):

#include "taiko_hit_led.h"

#include <stdbool.h>
#include <stddef.h>
#include <stdint.h>

#include "driver/gpio.h"
#include "driver/rmt_tx.h"
#include "esp_log.h"
#include "freertos/FreeRTOS.h"
#include "freertos/task.h"

#define HIT_LED_GPIO GPIO_NUM_38
#define HIT_LED_HOLD_MS 120U
#define HIT_LED_CHANNEL_LEVEL 96U
#define HIT_LED_RMT_RESOLUTION_HZ 10000000U
#define HIT_LED_RMT_SYMBOLS 64U
#define HIT_LED_TX_TIMEOUT_MS 10
#define HIT_LED_TASK_STACK_SIZE 3072U
#define HIT_LED_TASK_PRIORITY 1U

#ifdef CONFIG_FREERTOS_UNICORE
#define HIT_LED_TASK_CORE 0
#else
#define HIT_LED_TASK_CORE 1
#endif

enum {
    HIT_LED_EVENT_DON = 1U << 0,
    HIT_LED_EVENT_KA = 1U << 1,
};

static const char *TAG = "taiko_hit_led";
static TaskHandle_t s_hit_led_task_handle;

// The supplied XL-5050RGBC-WS2812B datasheet identifies bits by their high
// time. These values also keep the complete frame near its specified 800 kHz
// data rate.
static const DRAM_ATTR rmt_symbol_word_t kWs2812Zero = {
    .level0 = 1,
    .duration0 = 3,  // 0.3 us high
    .level1 = 0,
    .duration1 = 9,  // 0.9 us low
};

static const DRAM_ATTR rmt_symbol_word_t kWs2812One = {
    .level0 = 1,
    .duration0 = 9,  // 0.9 us high
    .level1 = 0,
    .duration1 = 3,  // 0.3 us low
};

static const DRAM_ATTR rmt_symbol_word_t kWs2812Reset = {
    .level0 = 0,
    .duration0 = 500,  // 50 us low
    .level1 = 0,
    .duration1 = 500,  // 50 us low
};

static size_t RMT_ENCODER_FUNC_ATTR encode_led_frame(
    const void *data,
    size_t data_size,
    size_t symbols_written,
    size_t symbols_free,
    rmt_symbol_word_t *symbols,
    bool *done,
    void *argument) {
    (void)argument;

    // A byte needs eight symbols. Waiting for the same space before appending
    // the reset symbol keeps the callback state derivable from symbols_written.
    if (symbols_free < 8) {
        return 0;
    }

    const size_t byte_index = symbols_written / 8;
    if (byte_index < data_size) {
        const uint8_t byte = ((const uint8_t *)data)[byte_index];
        for (size_t bit = 0; bit < 8; ++bit) {
            const uint8_t mask = (uint8_t)(0x80U >> bit);
            symbols[bit] =
                (byte & mask) != 0 ? kWs2812One : kWs2812Zero;
        }
        return 8;
    }

    // The datasheet asks for at least 100 us low, even though its timing table
    // separately lists 80 us. Use the stricter value.
    symbols[0] = kWs2812Reset;
    *done = true;
    return 1;
}

static esp_err_t init_led_rmt(rmt_channel_handle_t *channel,
                              rmt_encoder_handle_t *encoder) {
    const rmt_tx_channel_config_t channel_config = {
        .gpio_num = HIT_LED_GPIO,
        .clk_src = RMT_CLK_SRC_DEFAULT,
        .resolution_hz = HIT_LED_RMT_RESOLUTION_HZ,
        .mem_block_symbols = HIT_LED_RMT_SYMBOLS,
        .trans_queue_depth = 1,
        .intr_priority = 0,
        .flags = {
            .init_level = 0,
        },
    };
    esp_err_t result = rmt_new_tx_channel(&channel_config, channel);
    if (result != ESP_OK) {
        return result;
    }

    const rmt_simple_encoder_config_t encoder_config = {
        .callback = encode_led_frame,
        .min_chunk_size = 8,
    };
    result = rmt_new_simple_encoder(&encoder_config, encoder);
    if (result != ESP_OK) {
        rmt_del_channel(*channel);
        *channel = NULL;
        return result;
    }

    result = rmt_enable(*channel);
    if (result != ESP_OK) {
        rmt_del_encoder(*encoder);
        rmt_del_channel(*channel);
        *encoder = NULL;
        *channel = NULL;
    }
    return result;
}

static esp_err_t write_led_color(rmt_channel_handle_t channel,
                                 rmt_encoder_handle_t encoder,
                                 uint32_t active_colors) {
    // The device consumes one pixel as G, R, B, most-significant bit first.
    const uint8_t grb[3] = {
        0,
        (active_colors & HIT_LED_EVENT_DON) != 0
            ? HIT_LED_CHANNEL_LEVEL
            : 0,
        (active_colors & HIT_LED_EVENT_KA) != 0
            ? HIT_LED_CHANNEL_LEVEL
            : 0,
    };
    const rmt_transmit_config_t transmit_config = {
        .loop_count = 0,
        .flags = {
            .eot_level = 0,
        },
    };

    esp_err_t result =
        rmt_transmit(channel, encoder, grb, sizeof(grb), &transmit_config);
    if (result == ESP_OK) {
        result =
            rmt_tx_wait_all_done(channel, HIT_LED_TX_TIMEOUT_MS);
    }
    return result;
}

static bool deadline_reached(TickType_t now, TickType_t deadline) {
    return (int32_t)(now - deadline) >= 0;
}

static TickType_t next_deadline_wait(TickType_t now,
                                     bool don_active,
                                     TickType_t don_until,
                                     bool ka_active,
                                     TickType_t ka_until) {
    TickType_t wait = portMAX_DELAY;
    if (don_active) {
        wait = don_until - now;
    }
    if (ka_active) {
        const TickType_t ka_wait = ka_until - now;
        if (wait == portMAX_DELAY || ka_wait < wait) {
            wait = ka_wait;
        }
    }
    return wait == 0 ? 1 : wait;
}
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

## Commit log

2016-03-29 Upload EPS file for the PCB
    [sanro.brd, sanro.sch]
2016-03-29 Arduino module library for Eagle
2017-03-09 Update sanro.ino
    Minor changes.
    -------------------------
    怕不是摸爆了，周末春假开始继续吧。
2017-11-22 勃爆，不做二五仔
2017-11-24 精致睡眠
2017-11-25 调参数肝爆了，暂时先摸了
2023-12-22 Update... everything?
    [sanro.brd, sanro.sch]
2023-12-22 Create ESP32 branch
2023-12-25 Moved ESP32 to main branch
2023-12-31 Added ESP32-S3
2024-01-02 Minor pin number change
2024-01-19 Change pin
2024-01-24 Revert to the original pin
2024-01-25 Remove LEDs and bugfix
2024-01-25 泰勒展开yyds
2024-01-27 Update PCB production files
    [BOM_PCB_Taiko Controller_2_2024-01-26.csv]
2026-05-03 Refactor controller firmware for ESP32-S3 DMA (#30)
    * Cleanup
    * Refactor
    * Cleanup
    * Default CONFIG_TINYUSB_HID_COUNT to 1
    * Complete refactor
    * README checkpoint
    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
    [BOM_PCB_Taiko Controller_2_2024-01-26.csv, Taiko_DMA_BOM.xlsx]
2026-05-14 Add 3D printing files and update banner image
    [3D_Print_Shell.3mf]
2026-05-14 Update 3MF file
    [3D_Print_Shell.3mf]
2026-05-14 Add more instructions
    [3D_Print_Shell.3mf]
2026-05-17 Minor fix to 3MF file
    [3D_Print_Shell.3mf]
